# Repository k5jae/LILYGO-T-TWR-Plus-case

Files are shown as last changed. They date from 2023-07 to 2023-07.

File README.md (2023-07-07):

# LILYGO-T-TWR-Plus-case

License: GPLv2

## Rationale

The T-TWR Plus has some unique features that made this case desirable. Since LILYGO has released the OpenEdition, we now have a unique M17 capable device. For more information go to M17 (https://m17project.org) and OpenRTX (https://openrtx.org). This case was designed in support of those projects. It was designed in FreeCAD Link branch version 2023.321.

Note: The audio speaker is behind the display shell and audio quality and levels have not yet been determined when the device is fully encased. Testing will take place by 15JUL23. Also, there is currently no battery cover which is still TBD.

## Printing Steps

Print the following (from the stl directory of this repository):
1. LILYGO-T-TWR-Plus-case-bottom.stl*
2. LILYGO-T-TWR-Plus-case-top.stl*
3. LILYGO-T-TWR-Plus-case-buttons.stl
4. 2x Spacer_8_5mm.stl (Only if not using the Pogostick)

\* Pogostick USB port is not exposed in these files use the following instead:
* LILYGO-T-TWR-Plus-case-bottom_pogostick.stl
* LILYGO-T-TWR-Plus-case-top_pogostick.stl

The spacers are to hold the space for the missing PogoStick board, which will be available to program the T-TWR Plus. There have been good results using supports for counterbores which pop out with a small screwdriver.

Note: The tolerances are fairly tight, so make sure you are using 0.2 mm layer height with high quality settings.

Testing so far:
* Prusa i3 MK3S with PLA and PETG, 100% infill
* Creality CR-6 SE with PLA

## Assembly Steps

### Prepare the T-TWR Plus
Prepare the T-TWR Plus for assembly by removing the two screws holding the display shell and drilling all of the holes with a 1/8" drill bit. This is due to the board using M2.5 screws, and the case is defined as using M3 screws. M3 nylon screws are more secure than M2.5. The drilling steps are easy if you take your time. Normally using a sharp drill bit in reverse is gentle enough to cause no damage.

For the lower holes, drill to the halfway point and flip the board over to finish (this keeps it nice and clean)
For the upper holes (with the display shell), use start at the back (PCB on top) and drill in reverse until through PCB and then switch to forward direction through the acrylic. Fast speed, low pressure

### Assembly

The spacers are to be used when the Pogostick programming board is not installed. The spacers go between the top case and the PCB next to the Wifi/BT module. When installing the Pogostick board, install with USB port down (ie all components underneath). Also ensure that the STL file you are printing has the USB port exposed.

The screws are defined as Nylon M3, with a minimum length of 25 mm. The upper screws should go through the display shell, T-TWR Plus PCB, and bottom case. The lower screws should go all the way through the top case, Pogostick (or spacers), T-TWR Plus PCB, bottom case. The bottom case has a counter bore for a nylon hex nut.

## Views

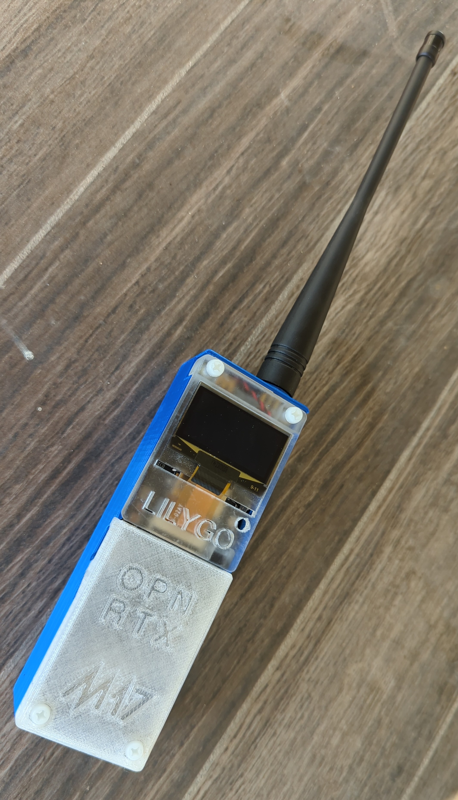
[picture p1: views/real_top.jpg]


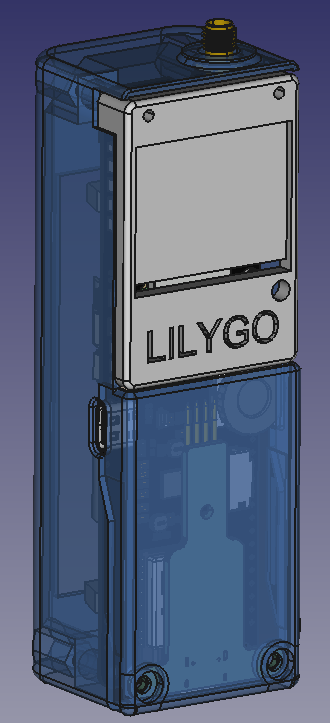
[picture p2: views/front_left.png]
||
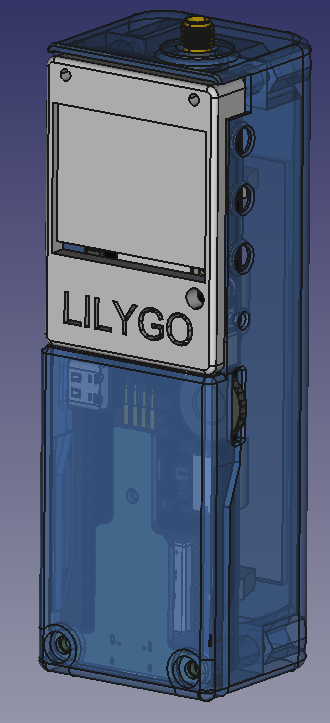
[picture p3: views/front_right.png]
|

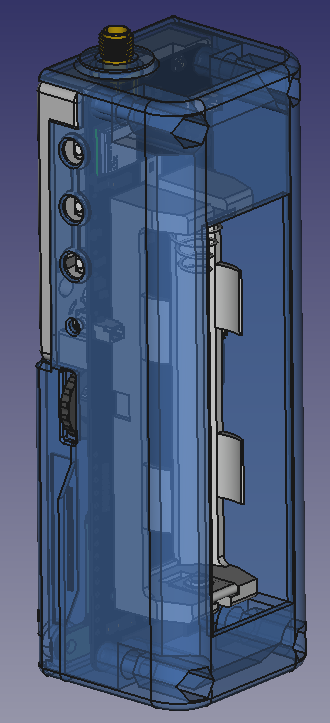
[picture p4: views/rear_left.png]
||
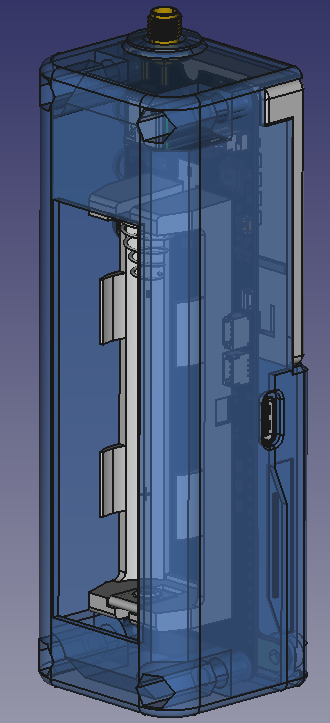
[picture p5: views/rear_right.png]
|

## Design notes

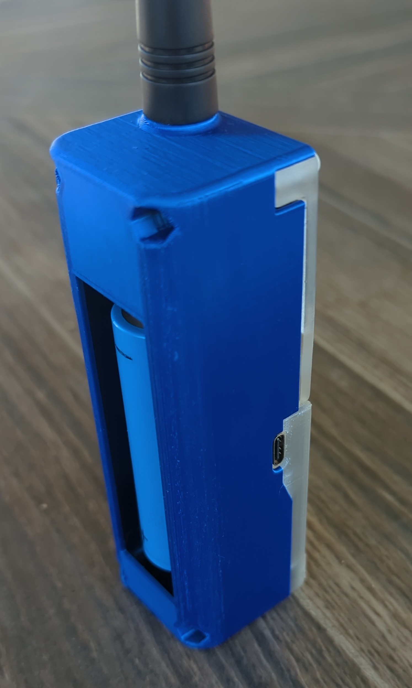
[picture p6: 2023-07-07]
views/real_back_right.jpg

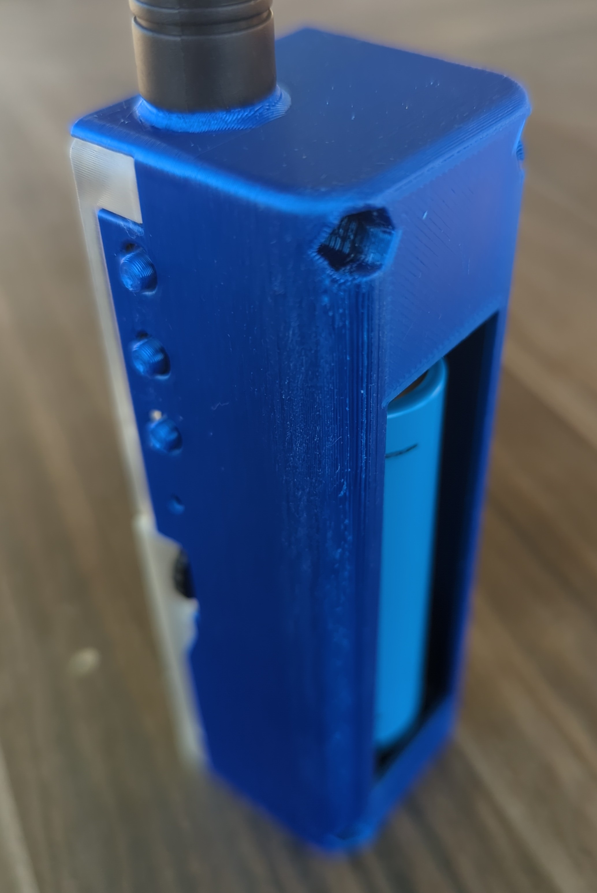
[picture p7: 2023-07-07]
views/real_back_left.jpg

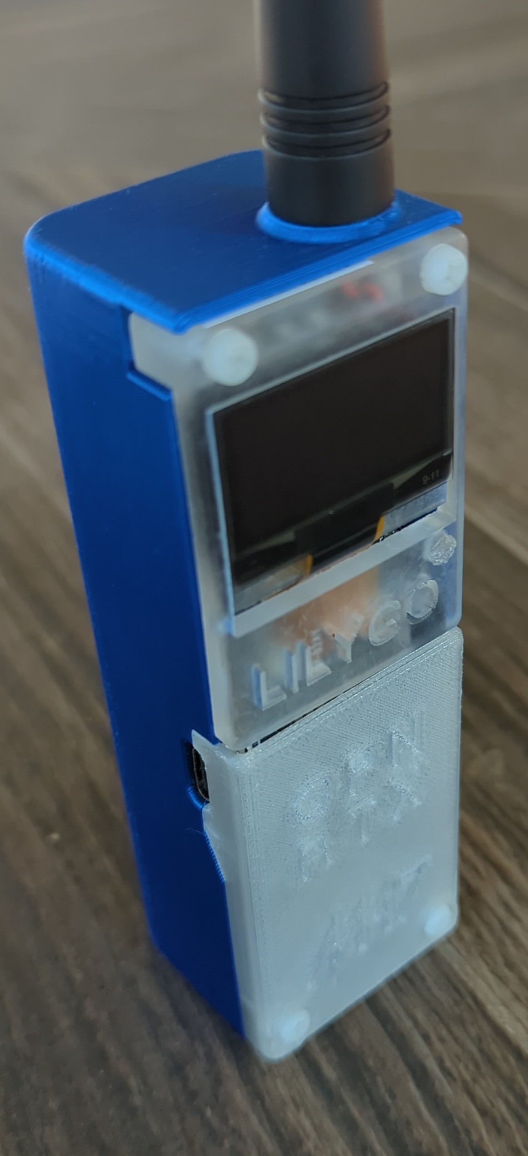
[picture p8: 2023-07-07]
views/real_front_left.jpg

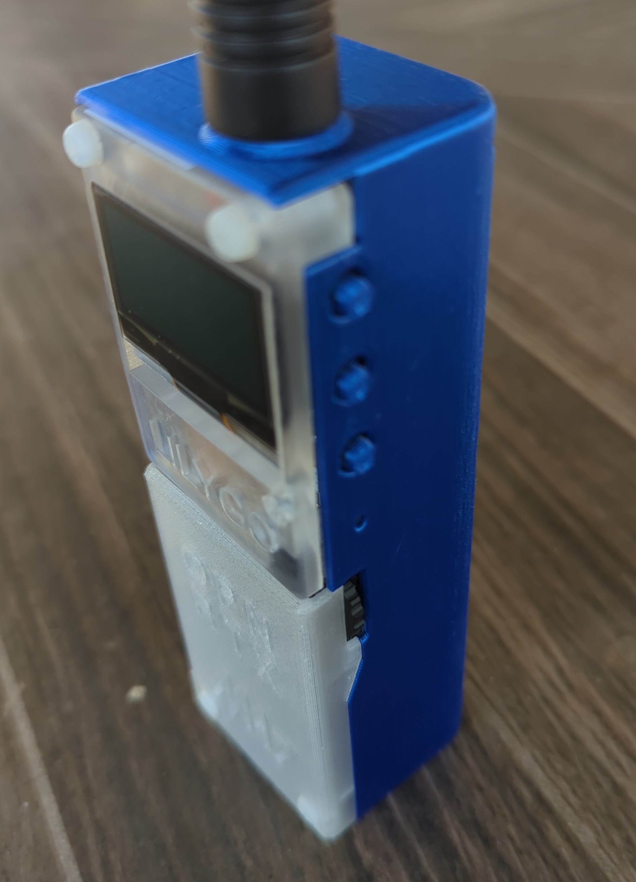
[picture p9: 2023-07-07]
views/real_front_right.jpg

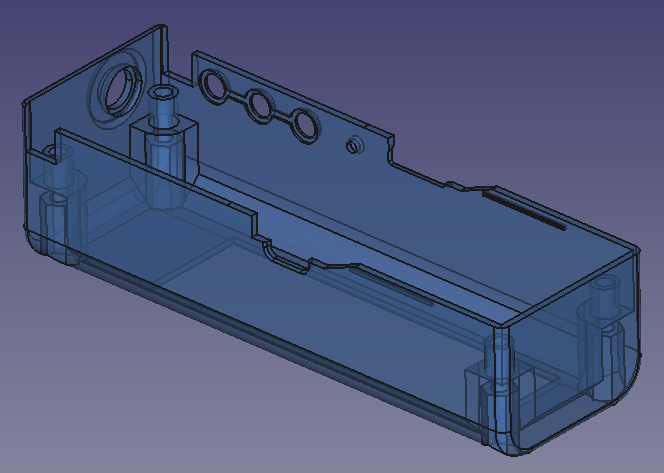
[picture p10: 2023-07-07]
views/case_bottom.png

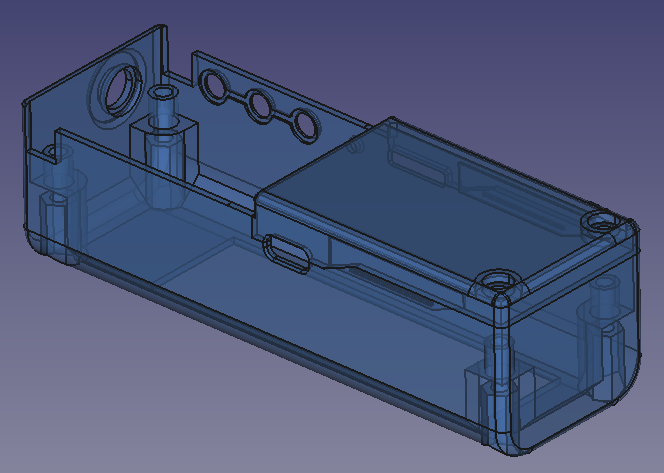
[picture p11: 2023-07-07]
views/empty_case.png

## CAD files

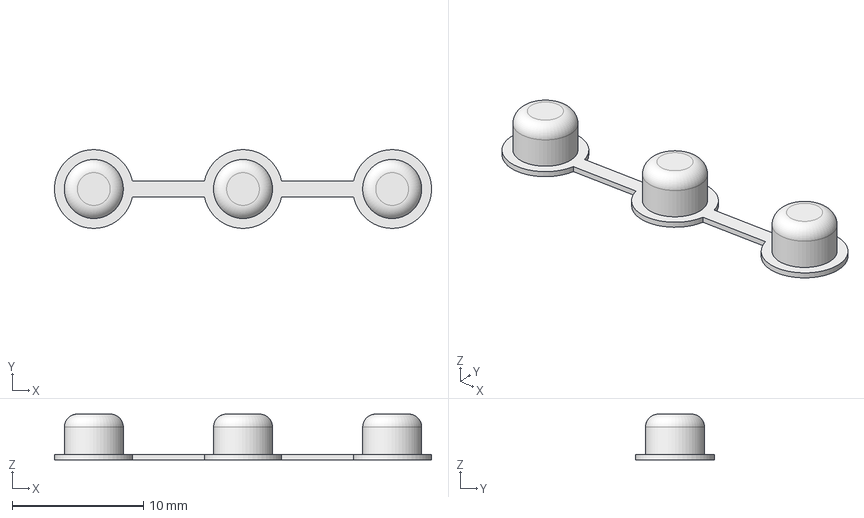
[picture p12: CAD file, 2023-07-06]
LilyGO-T-TWR-Plus-buttons.FCStd
28.7 x 6.00 x 3.50 mm

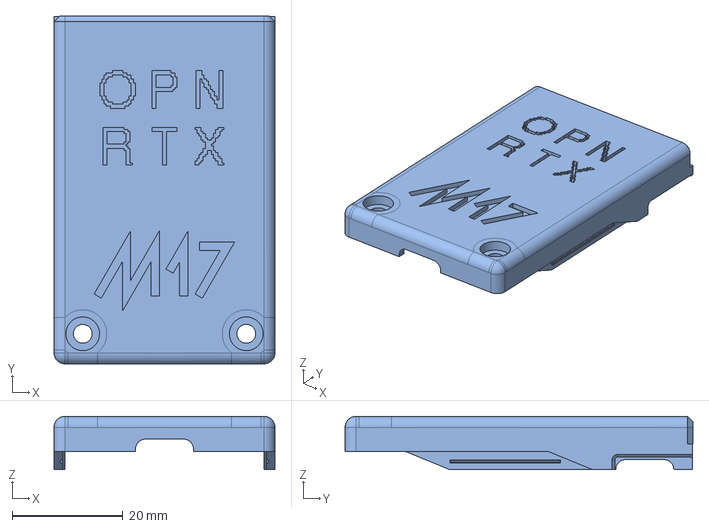
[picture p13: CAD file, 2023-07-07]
step/LILYGO-T-TWR-Plus-case-top_pogostick.step
40.0 x 63.0 x 9.66 mm

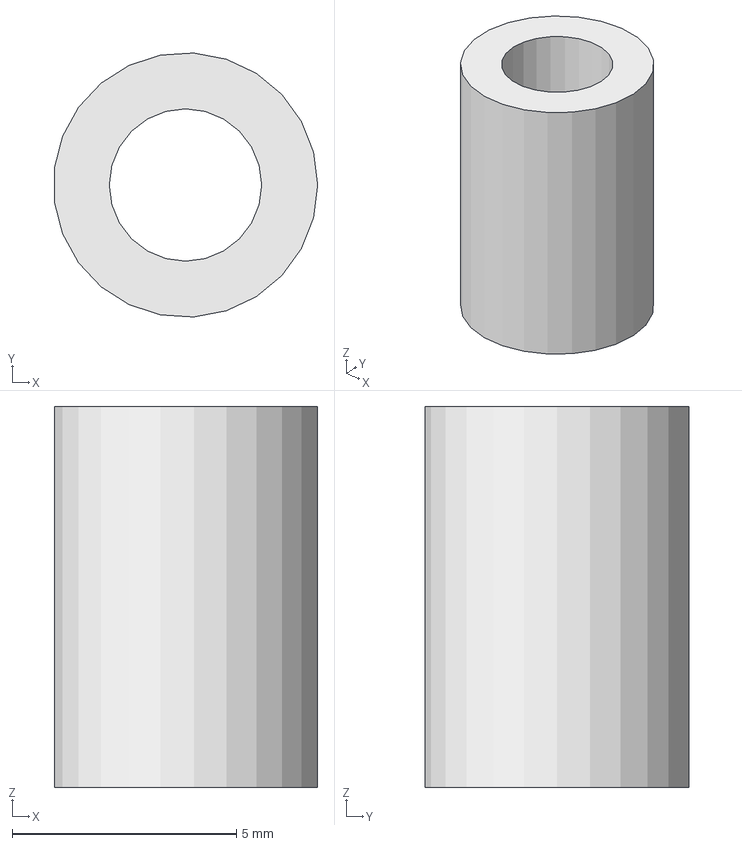
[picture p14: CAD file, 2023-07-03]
Spacer_8_5mm.FCStd
5.88 x 5.89 x 8.50 mm

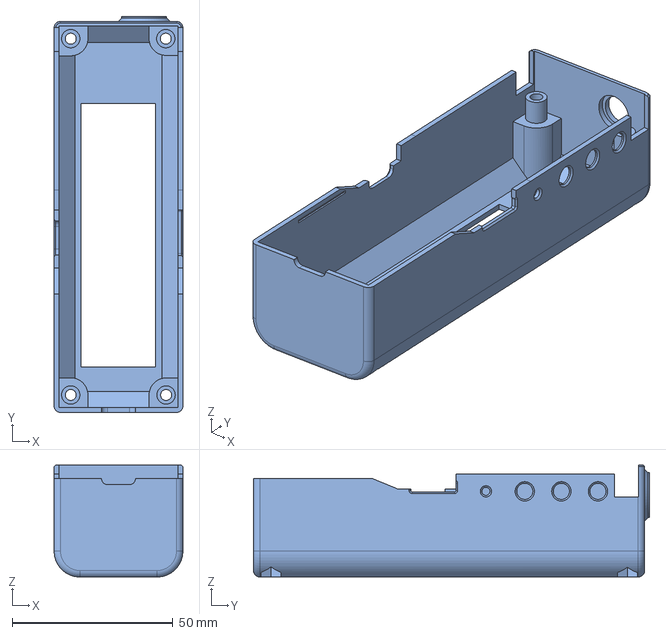
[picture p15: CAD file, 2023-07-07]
step/LILYGO-T-TWR-Plus-case-bottom_pogostick.step
40.0 x 123.0 x 34.8 mm

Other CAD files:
step/LILYGO-T-TWR-Plus-case-bottom.step
step/LILYGO-T-TWR-Plus-case-buttons.step
step/LILYGO-T-TWR-Plus-case-top.step
stl/LILYGO-T-TWR-Plus-case-bottom.stl
stl/LILYGO-T-TWR-Plus-case-bottom_pogostick.stl
stl/LILYGO-T-TWR-Plus-case-buttons.stl
stl/LILYGO-T-TWR-Plus-case-top.stl
stl/LILYGO-T-TWR-Plus-case-top_pogostick.stl
stl/Spacer_8_5mm.stl

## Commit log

2023-06-28 [WIP] T-TWR Plus Case
    [LILYGO-T-TWR-Plus-case.step, LILYGO-T-TWR-Plus-case.stl]
2023-07-03 [WIP] Refined ports and split case.
    [LILYGO-T-TWR-Plus-case-back.step, LILYGO-T-TWR-Plus-case-back.stl, LILYGO-T-TWR-Plus-case-front.step]
2023-07-03 Added front cover holes
2023-07-03 Updated separation plane
    [LILYGO-T-TWR-Plus-case-back.step, LILYGO-T-TWR-Plus-case-front.step]
2023-07-03 Updated case.
    [LILYGO-T-TWR-Plus-case-back.step, LILYGO-T-TWR-Plus-case-back.stl, LILYGO-T-TWR-Plus-case-front.step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]
2023-07-03 Changed spacer height.
    [Spacer_8_5mm.FCStd, Spacer_8_5mm.stl, Spacer_9mm.FCStd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]
2023-07-04 Added real buttons to design.
    [LILYGO-T-TWR-Plus-case-back.step, LILYGO-T-TWR-Plus-case-back.stl, LILYGO-T-TWR-Plus-case-buttons_lg.stl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]
2023-07-04 Added key/notch to top and bottom case interface.
    [LILYGO-T-TWR-Plus-case-back.step, LILYGO-T-TWR-Plus-case-back.stl, LILYGO-T-TWR-Plus-case-bottom.step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]
2023-07-04 widened hex nut counter bore by 0.1mm
    [LILYGO-T-TWR-Plus-case-bottom.step, LILYGO-T-TWR-Plus-case-bottom.stl, LILYGO-T-TWR-Plus-case-top.step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]
2023-07-04 Added pogostick configuration (USB port opening)
    [LILYGO-T-TWR-Plus-case-bottom_pogostick.step, LILYGO-T-TWR-Plus-case-bottom_pogostick.stl, LILYGO-T-TWR-Plus-case-top_pogostick.step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]
2023-07-05 Added OPNRTX and M17 logos into top case
    [LILYGO-T-TWR-Plus-case-top.step, LILYGO-T-TWR-Plus-case-top.stl, LILYGO-T-TWR-Plus-case-top_pogostick.step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]
2023-07-06 Made the text embossed deeper (1 mm now)
    [LILYGO-T-TWR-Plus-case-top.step, LILYGO-T-TWR-Plus-case-top.stl]
2023-07-06 Extend bottom of case to cover battery.
    [LILYGO-T-TWR-Plus-case-bottom.step, LILYGO-T-TWR-Plus-case-bottom.stl, LILYGO-T-TWR-Plus-case-top.step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]
2023-07-06 Updated bottom case and buttons
    Reset button is now just a port.
    [LILYGO-T-TWR-Plus-case-bottom.step, LILYGO-T-TWR-Plus-case-bottom.stl, LILYGO-T-TWR-Plus-case-buttons.step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]
2023-07-07 Updated pogostick design
    with new parameters for buttons and rounded back
    [LILYGO-T-TWR-Plus-case-bottom_pogostick.step, LILYGO-T-TWR-Plus-case-bottom_pogostick.stl, LILYGO-T-TWR-Plus-case-buttons_lg.stl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]
